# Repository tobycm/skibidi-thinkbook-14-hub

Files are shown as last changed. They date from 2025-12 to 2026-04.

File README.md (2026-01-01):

# skibidi thinkbook 14 hub

a very skibidi usb hub to clip on my laptop.

features:

- usb 3.2 gen 1 hub with gigabit ethernet
- 2 usb-a usb 3.2 gen 1 ports
- 2 usb-c usb 2.0 ports
- 3.5mm audio jack

powered by tusb8042a usb hub controller, rtl8153b gigabit ethernet controller, ch334 usb 2.0 hub controller, and pcm2704 usb dac.

designed in kicad 9

## PCB

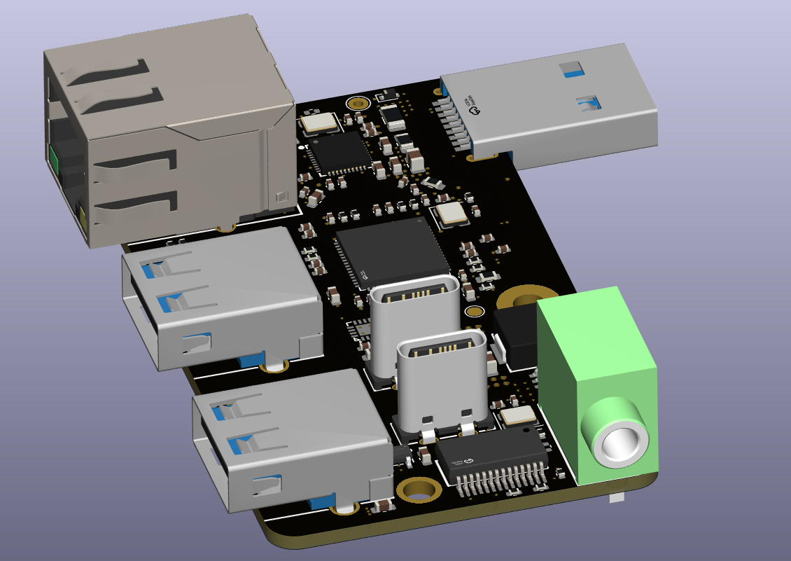
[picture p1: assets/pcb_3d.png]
pcb 3d


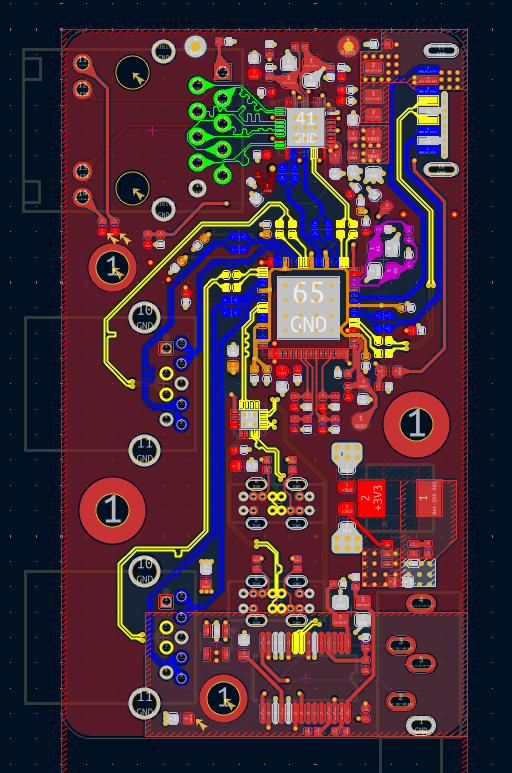
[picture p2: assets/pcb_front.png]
pcb front


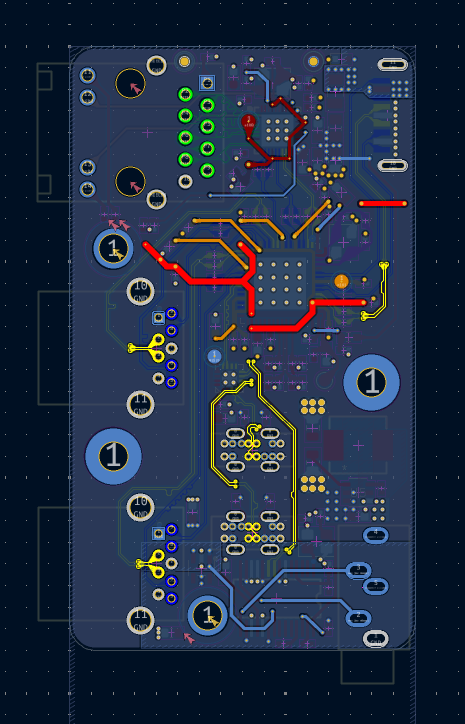
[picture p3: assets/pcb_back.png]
pcb back


## CAD

### Case

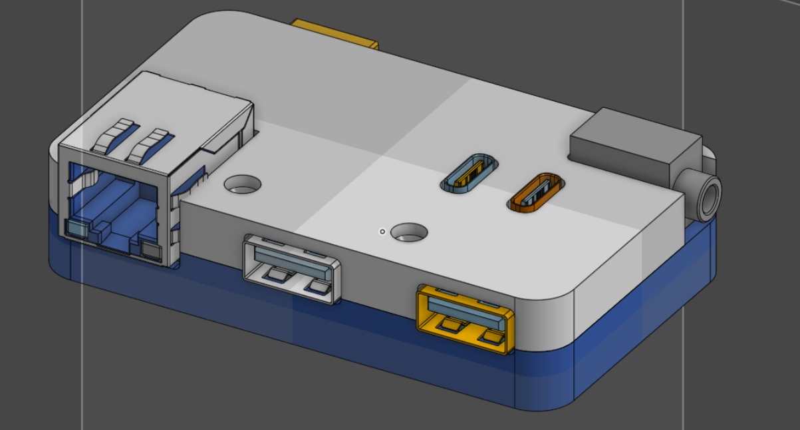
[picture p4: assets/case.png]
case


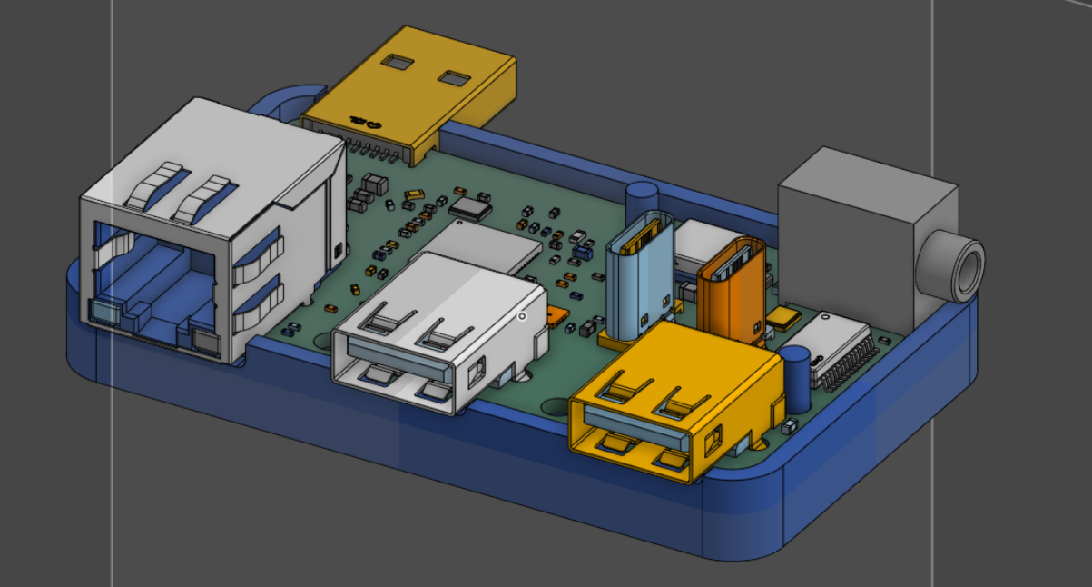
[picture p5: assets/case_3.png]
case 3


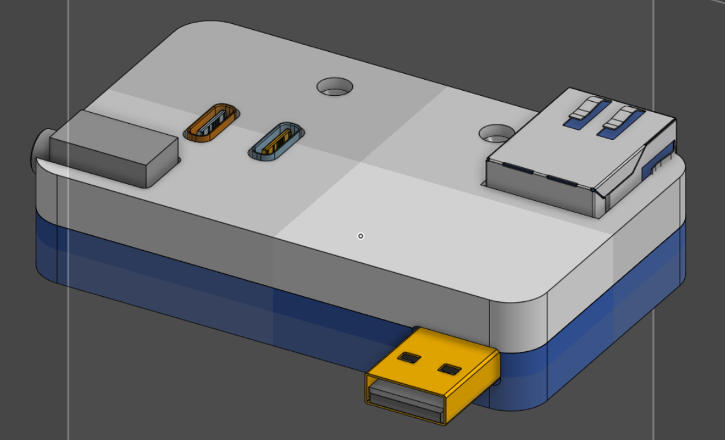
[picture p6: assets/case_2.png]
case 2


### Body

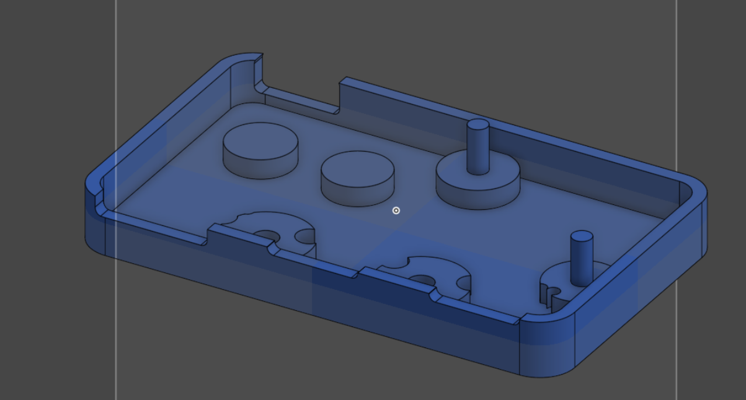
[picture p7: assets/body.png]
body


### Top

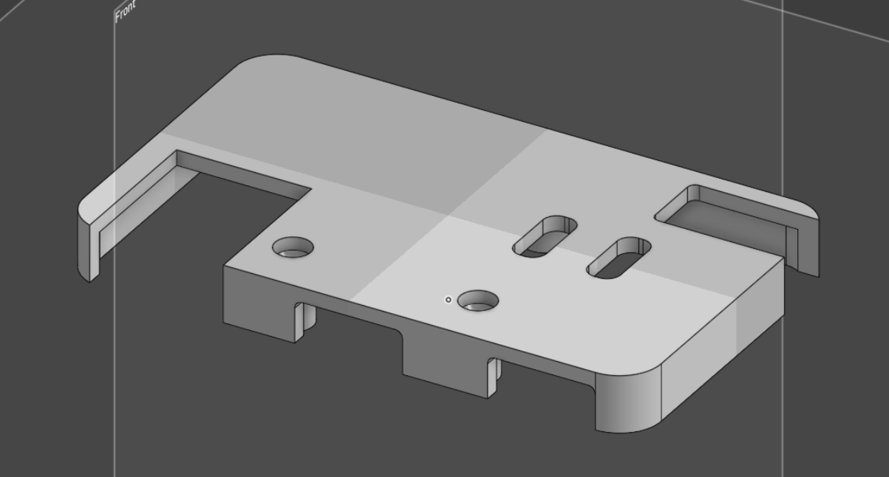
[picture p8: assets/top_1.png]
top 1


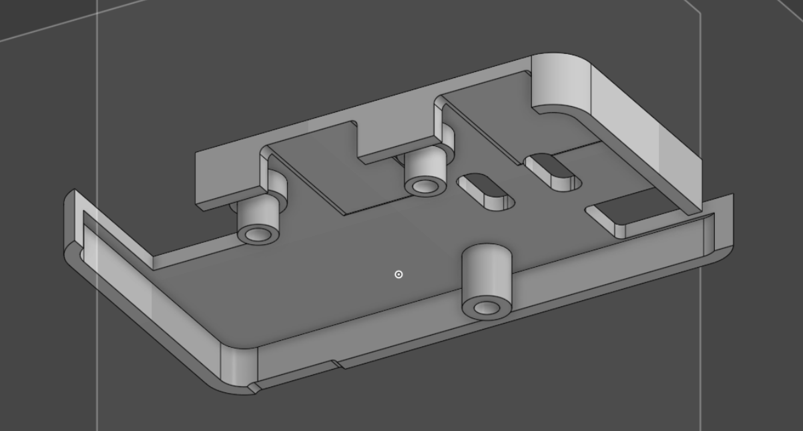
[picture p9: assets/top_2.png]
top 2


## BOM

| Item | Quantity | Total Cost | Vendor |
| :--- | :--- | :--- | :--- |
| PCB | 5 | $11.90 | JLCPCB |
| PCBA | 2 | $59.26 | JLCPCB |
| JLCPCB Shipping | 1 | $8.29 | JLCPCB |
| PJ-325C5-G | 5 | $0.90 | LCSC |
| ESD5Z5.0T1G | 20 | $0.67 | LCSC |
| BSMD1206-200-12V | 10 | $0.61 | LCSC |
| BLM21PG221SN1D | 50 | $0.83 | LCSC |
| HR911130C | 3 | $7.68 | LCSC |
| ME6211C33M5G-N | 10 | $0.47 | LCSC |
| 0603WAF4302T5E | 100 | $0.12 | LCSC |
| FRC0603F9531TS | 100 | $0.09 | LCSC |
| 0402WGF2491TCE | 200 | $0.12 | LCSC |
| HC-USB3.0-C26 | 5 | $0.53 | LCSC |
| CYA0650-4.7UH | 5 | $1.28 | LCSC |
| HC-ST-003-01-J | 20 | $2.49 | LCSC |
| TYPE-C 14PLC-H10.0 | 20 | $4.68 | LCSC |
| XL2EL89COI-111YLC-24M | 10 | $0.65 | LCSC |
| XL2EL89COI-111YLC-12M | 10 | $0.67 | LCSC |
| LCSC Shipping | 1 | $16.09 | LCSC |
| Round Hex Cap Screw kit M3 | 1 | $8.52 | Aliexpress |
| Brass Threaded Insert Nut Kit M3 | 1 | $10.54 | Aliexpress |
| **Grand Total** | **-** | **$136.39** | **-** |

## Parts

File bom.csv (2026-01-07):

Item | Quantity | Total Cost | Vendor | Link | Description
PCB | 5 | $11.90 | JLCPCB | https://jlcpcb.com/
PCBA | 2 | $59.26 | JLCPCB
JLCPCB Shipping | 1 | $8.29 | JLCPCB
PJ-325C5-G | 5 | $0.90 | LCSC | https://www.lcsc.com/product-detail/C692438.html | 3.5mm Headphone Jack 0.5A 30V Through Hole
ESD5Z5.0T1G | 20 | $0.67 | LCSC | https://www.lcsc.com/product-detail/C82044.html | 18.6VC Clamp 9.4A@8/20us Ipp ESD DIODE SOD-523
BSMD1206-200-12V | 10 | $0.61 | LCSC | https://www.lcsc.com/product-detail/C883135.html | Polymeric PTC Resettable Fuse 12V 2A Surface Mount 1206
BLM21PG221SN1D | 50 | $0.83 | LCSC | https://www.lcsc.com/product-detail/C85840.html | 220Ω@100MHz 1 Line Ferrite Bead 0805 2A 45mΩ
HR911130C | 3 | $7.68 | LCSC | https://www.lcsc.com/product-detail/C50933.html | Jack Modular Connector RJ45 Through Hole, Right Angle Shielded
ME6211C33M5G-N | 10 | $0.47 | LCSC | https://www.lcsc.com/product-detail/C82942.html | Positive Fixed 3.3V SOT-23-5 Voltage Regulators - Linear, Low Drop Out (LDO) Regulators RoHS
0603WAF4302T5E | 100 | $0.12 | LCSC | https://www.lcsc.com/product-detail/C23172.html | 43kΩ ±1% 100mW 0603 Thick Film Resistor
FRC0603F9531TS | 100 | $0.09 | LCSC | https://www.lcsc.com/product-detail/C2960722.html | 9.53kΩ ±1% 100mW 0603 Thick Film Resistor
0402WGF2491TCE | 200 | $0.12 | LCSC | https://www.lcsc.com/product-detail/C25884.html | 2.49kΩ ±1% 62.5mW 0402 Thick Film Resistor
HC-USB3.0-C26 | 5 | $0.53 | LCSC | https://www.lcsc.com/product-detail/C7501854.html | USB-A (USB TYPE-A) Receptacle Connector 9 Position Recessed Mount
CYA0650-4.7UH | 5 | $1.28 | LCSC | https://www.lcsc.com/product-detail/C5189754.html | 6A 4.7uH ±20% 8A 26mΩ SMD,7.2x6.6mm Fixed Inductors RoHS
HC-ST-003-01-J | 20 | $2.49 | LCSC | https://www.lcsc.com/product-detail/C2845330.html | USB-A (USB TYPE-A) Receptacle Connector 9 Position Right Angle
TYPE-C 14PLC-H10.0 | 20 | $4.68 | LCSC | https://www.lcsc.com/product-detail/C3151746.html | USB-C (USB TYPE-C) Receptacle Connector 14 Position Through Hole
XL2EL89COI-111YLC-24M | 10 | $0.65 | LCSC | https://www.lcsc.com/product-detail/C5444545.html | Crystal 24MHz ±10ppm 12pF SMD3225-4P
XL2EL89COI-111YLC-12M | 10 | $0.67 | LCSC | https://www.lcsc.com/product-detail/C5280578.html | Crystal 12MHz ±10ppm 12pF SMD3225-4P
Caps | 100 | $1.00 | LCSC
LCSC Shipping | 1 | $16.09 | LCSC
Round Hex Cap Screw kit M3 | 1 | $8.52 | Aliexpress | https://www.aliexpress.com/item/1005007197683325.html
Brass Threaded Insert Nut Kit M3 | 1 | $10.54 | Aliexpress | https://www.aliexpress.com/item/1005006472962973.html
skibidi thinkbook 14 hub | 1 | $137.39 |  | https://github.com/tobycm/skibidi-thinkbook-14-hub

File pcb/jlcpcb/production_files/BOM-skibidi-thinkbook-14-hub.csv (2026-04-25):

Comment | Designator | Footprint | LCSC | Quantity
100n | C14,C15,C16,C17,C2,C22,C23,C24,C25,C26,C27,C28,C29,C3,C31,C32,C33,C34,C35,C36,C4,C40,C41,C47,C48,C49,C5,C51,C6,C7,C8,C9 | C_0402_1005Metric | C307331 | 32
10u | C1,C13,C20,C30,C39,C44,C50 | C_0603_1608Metric | C19702 | 7
18p | C11,C12,C37,C38,C45,C52 | C_0402_1005Metric | C1549 | 6
1M | R1 | R_0402_1005Metric | C26083 | 1
1u | C10,C19,C46,C53,C54,C55 | C_0603_1608Metric | C15849 | 6
22 | R10,R11,R12,R13,R16,R6,R7,R9 | R_0402_1005Metric | C25092 | 8
22u | C21,C42,C43 | C_0805_2012Metric | C45783 | 3
25Mhz | Y2 | Crystal_SMD_3225-4Pin_3.2x2.5mm | C9006 | 1
4.7k | R14,R17,R18,R2,R20,R21,R27,R28,R31,R32,R33,R34,R4,R8 | R_0402_1005Metric | C25900 | 14
470 | R24,R25 | R_0402_1005Metric | C25117 | 2
56k | R35,R36,R37,R38 | R_0402_1005Metric | C25796 | 4
AP63203WU-7 | U5 | AP63203WU-7_DIO | C780769 | 1
CH334P | U4 | QFN-16_L3.0-W3.0-P0.50-BL-EP1.7 | C5373042 | 1
PCM2704CDBR | U7 | SSOP-28_L10.2-W5.3-P0.65-LS7.8-BL | C2859784 | 1
RTL8153B-VB-CG | U3 | QFN-40_L5.0-W5.0-P0.40-BL-EP3.7 | C2802072 | 1
TUSB8042AIRGCR | U2 | VQFN-64_L9.0-W9.0-P0.50-TL-EP6.0 | C2860610 | 1

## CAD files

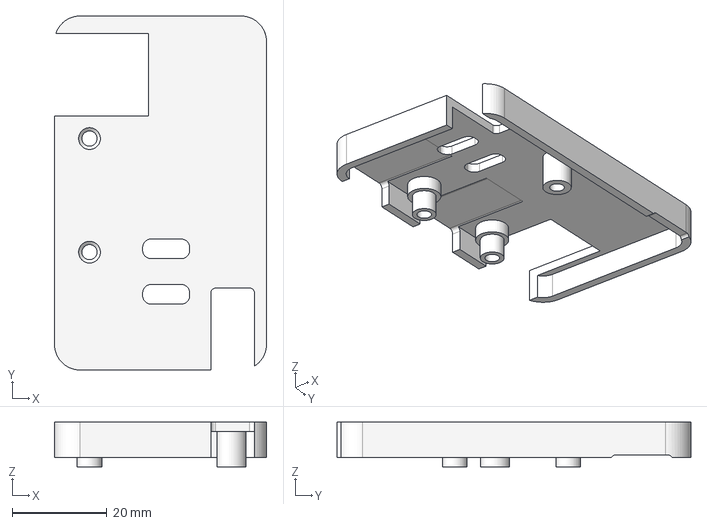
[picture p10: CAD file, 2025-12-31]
cad/top.step
44.8 x 74.8 x 9.48 mm

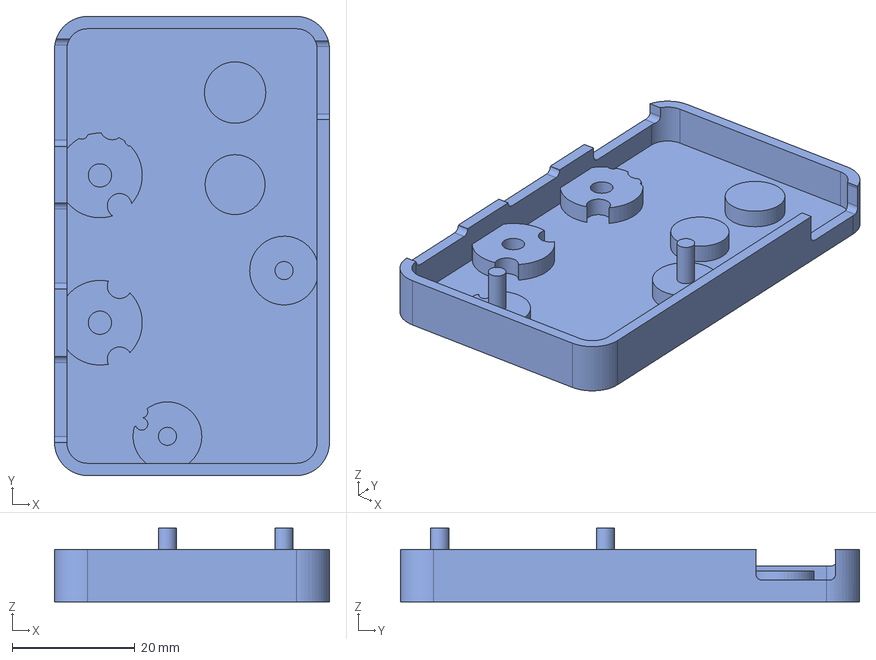
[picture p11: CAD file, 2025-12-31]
cad/body.step
44.8 x 74.8 x 12.0 mm

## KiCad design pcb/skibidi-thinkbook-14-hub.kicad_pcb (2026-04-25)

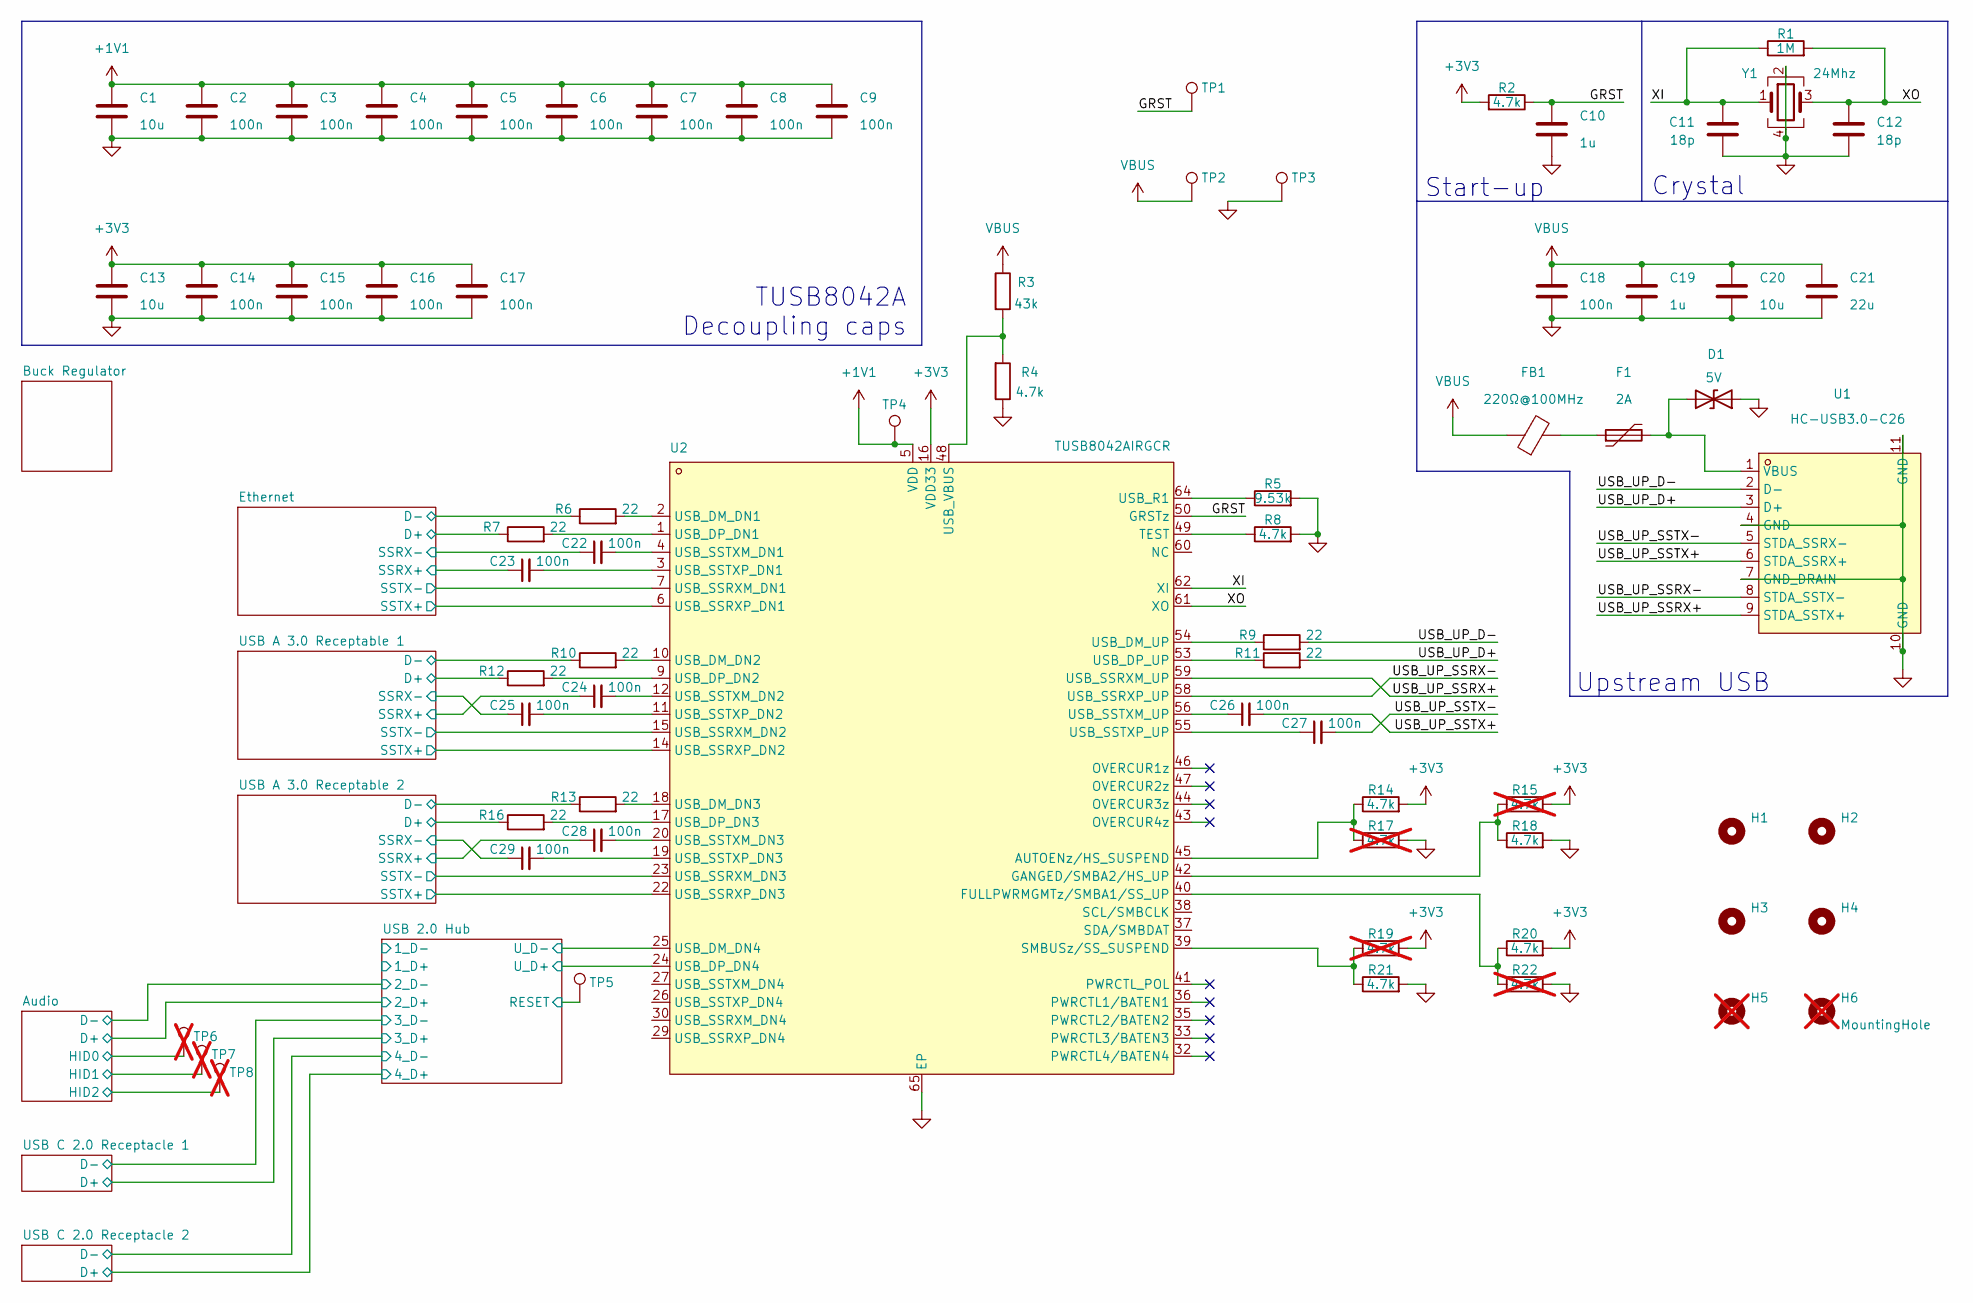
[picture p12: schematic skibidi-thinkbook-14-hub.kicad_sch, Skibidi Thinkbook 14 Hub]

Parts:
C1, C13, C20: 10u; C_0603_1608Metric; LCSC Part # C19702
C2, C3, C4, C5, C6, C7, C8, C9, C14, C15, C16, C17, C18, C22, C23, C24, C25, C26, C27, C28, C29: 100n; C_0402_1005Metric; LCSC Part # C307331
C10, C19: 1u; C_0603_1608Metric; LCSC Part # C15849
C11, C12: 18p; C_0402_1005Metric; LCSC Part # C1549
C21: 22u; C_0805_2012Metric; LCSC Part # C45783
D1: 5V; D_SOD-523; LCSC Part # C82044
F1: 2A; Fuse_1206_3216Metric; LCSC Part # C883135
FB1: 220Ω@100MHz; R_0805_2012Metric_Pad1.20x1.40mm_HandSolder; LCSC Part # C85840
H1, H2, H3, H4: MountingHole; MountingHole_3.2mm_M3_Pad
H5, H6: MountingHole; MountingHole_3.2mm_M3_Pad; not fitted
R1: 1M; R_0402_1005Metric; LCSC Part # C26083
R2, R4, R8, R14, R18, R20, R21: 4.7k; R_0402_1005Metric; LCSC Part # C25900
R3: 43k; R_0603_1608Metric; LCSC Part # C23172
R5: 9.53k; R_0603_1608Metric; LCSC Part # C2960722
R6, R7, R9, R10, R11, R12, R13, R16: 22; R_0402_1005Metric; LCSC Part # C25092
R15, R17, R19, R22: 4.7k; R_0402_1005Metric; LCSC Part # C25900; not fitted
TP1, TP4, TP5: TestPoint; TestPoint_Pad_D1.5mm
TP2, TP3: TestPoint; TestPoint_Pad_D2.0mm
TP6, TP7, TP8: TestPoint; TestPoint_Pad_D1.5mm; not fitted
U1: HC-USB3.0-C26; USB-3.0-A-SMD_HC-USB3.0-C26; LCSC Part C7501854
U2: TUSB8042AIRGCR; VQFN-64_L9.0-W9.0-P0.50-TL-EP6.0; LCSC Part C2860610
Y1: 24Mhz; Crystal_SMD_3225-4Pin_3.2x2.5mm; LCSC Part # C5444545

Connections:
+1V1: C1.1, C2.1, C3.1, C4.1, C5.1, C6.1, C7.1, C8.1, C9.1, TP4.1, U2.5 (VDD), U2.8 (VDD), U2.13 (VDD), U2.21 (VDD), U2.28 (VDD), U2.31 (VDD), U2.51 (VDD), U2.57 (VDD)
+3V3: C13.1, C14.1, C15.1, C16.1, C17.1, R2.2, R14.2, R15.2, R19.2, R20.2, U2.16 (VDD33), U2.34 (VDD33), U2.52 (VDD33), U2.63 (VDD33); also elsewhere on the board
/Ethernet/D+: R7.1; also elsewhere on the board
/Ethernet/D-: R6.1; also elsewhere on the board
/Ethernet/SSRX+: C23.1; also elsewhere on the board
/Ethernet/SSRX-: C22.1; also elsewhere on the board
/Ethernet/SSTX+: U2.6 (USB_SSRXP_DN1); also elsewhere on the board
/Ethernet/SSTX-: U2.7 (USB_SSRXM_DN1); also elsewhere on the board
/GRST: C10.1, R2.1, TP1.1, U2.50 (GRSTz)
/USB 2.0 Hub/RESET: TP5.1; also elsewhere on the board
/USB 2.0 Hub/U_D+: U2.24 (USB_DP_DN4); also elsewhere on the board
/USB 2.0 Hub/U_D-: U2.25 (USB_DM_DN4); also elsewhere on the board
/USB A 3.0 Receptable 1/D+: R12.1; also elsewhere on the board
/USB A 3.0 Receptable 1/D-: R10.1; also elsewhere on the board
/USB A 3.0 Receptable 1/SSRX+: C24.1; also elsewhere on the board
/USB A 3.0 Receptable 1/SSRX-: C25.1; also elsewhere on the board
/USB A 3.0 Receptable 1/SSTX+: U2.14 (USB_SSRXP_DN2); also elsewhere on the board
/USB A 3.0 Receptable 1/SSTX-: U2.15 (USB_SSRXM_DN2); also elsewhere on the board
/USB A 3.0 Receptable 2/D+: R16.1; also elsewhere on the board
/USB A 3.0 Receptable 2/D-: R13.1; also elsewhere on the board
/USB A 3.0 Receptable 2/SSRX+: C28.1; also elsewhere on the board
/USB A 3.0 Receptable 2/SSRX-: C29.1; also elsewhere on the board
/USB A 3.0 Receptable 2/SSTX+: U2.22 (USB_SSRXP_DN3); also elsewhere on the board
/USB A 3.0 Receptable 2/SSTX-: U2.23 (USB_SSRXM_DN3); also elsewhere on the board
/USB_UP_D+: R11.2, U1.3 (D+)
/USB_UP_D-: R9.2, U1.2 (D-)
/USB_UP_SSRX+: U1.9 (STDA_SSTX+), U2.59 (USB_SSRXM_UP)
/USB_UP_SSRX-: U1.8 (STDA_SSTX-), U2.58 (USB_SSRXP_UP)
/USB_UP_SSTX+: C26.2, U1.6 (STDA_SSRX+)
/USB_UP_SSTX-: C27.2, U1.5 (STDA_SSRX-)
/XI: C11.1, R1.1, U2.62 (XI), Y1.1
/XO: C12.1, R1.2, U2.61 (XO), Y1.3
GND: C1.2, C2.2, C3.2, C4.2, C5.2, C6.2, C7.2, C8.2, C9.2, C10.2, C11.2, C12.2, C13.2, C14.2, C15.2, C16.2, C17.2, C18.2, C19.2, C20.2, C21.2, D1.1 (A1), R4.1, R5.2, R8.2, R17.2, R18.2, R21.2, R22.2, TP3.1, U1.4 (GND), U1.7 (GND_DRAIN), U1.10 (GND), U1.11 (GND), U2.65 (EP), Y1.2, Y1.4; also elsewhere on the board
unnamed: D1.2 (A2), F1.2, U1.1 (VBUS)
unnamed: F1.1, FB1.2
unnamed: R14.1, R17.1, U2.45 (AUTOENz/HS_SUSPEND)
unnamed: R20.1, R22.1, U2.40 (FULLPWRMGMTz/SMBA1/SS_UP)
unnamed: R15.1, R18.1, U2.42 (GANGED/SMBA2/HS_UP)
unnamed: R19.1, R21.1, U2.39 (SMBUSz/SS_SUSPEND)
unnamed: R8.1, U2.49 (TEST)
unnamed: R6.2, U2.2 (USB_DM_DN1)
unnamed: R10.2, U2.10 (USB_DM_DN2)
unnamed: R13.2, U2.18 (USB_DM_DN3)
unnamed: R9.1, U2.54 (USB_DM_UP)
unnamed: R7.2, U2.1 (USB_DP_DN1)
unnamed: R12.2, U2.9 (USB_DP_DN2)
unnamed: R16.2, U2.17 (USB_DP_DN3)
unnamed: R11.1, U2.53 (USB_DP_UP)
unnamed: R5.1, U2.64 (USB_R1)
unnamed: C22.2, U2.4 (USB_SSTXM_DN1)
unnamed: C24.2, U2.12 (USB_SSTXM_DN2)
unnamed: C28.2, U2.20 (USB_SSTXM_DN3)
unnamed: C26.1, U2.56 (USB_SSTXM_UP)
unnamed: C23.2, U2.3 (USB_SSTXP_DN1)
unnamed: C25.2, U2.11 (USB_SSTXP_DN2)
unnamed: C29.2, U2.19 (USB_SSTXP_DN3)
unnamed: C27.1, U2.55 (USB_SSTXP_UP)
unnamed: R3.2, R4.2, U2.48 (USB_VBUS)
VBUS: C18.1, C19.1, C20.1, C21.1, FB1.1, R3.1, TP2.1; also elsewhere on the board

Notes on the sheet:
TUSB8042A Decoupling caps
Start-up
Crystal
Upstream USB

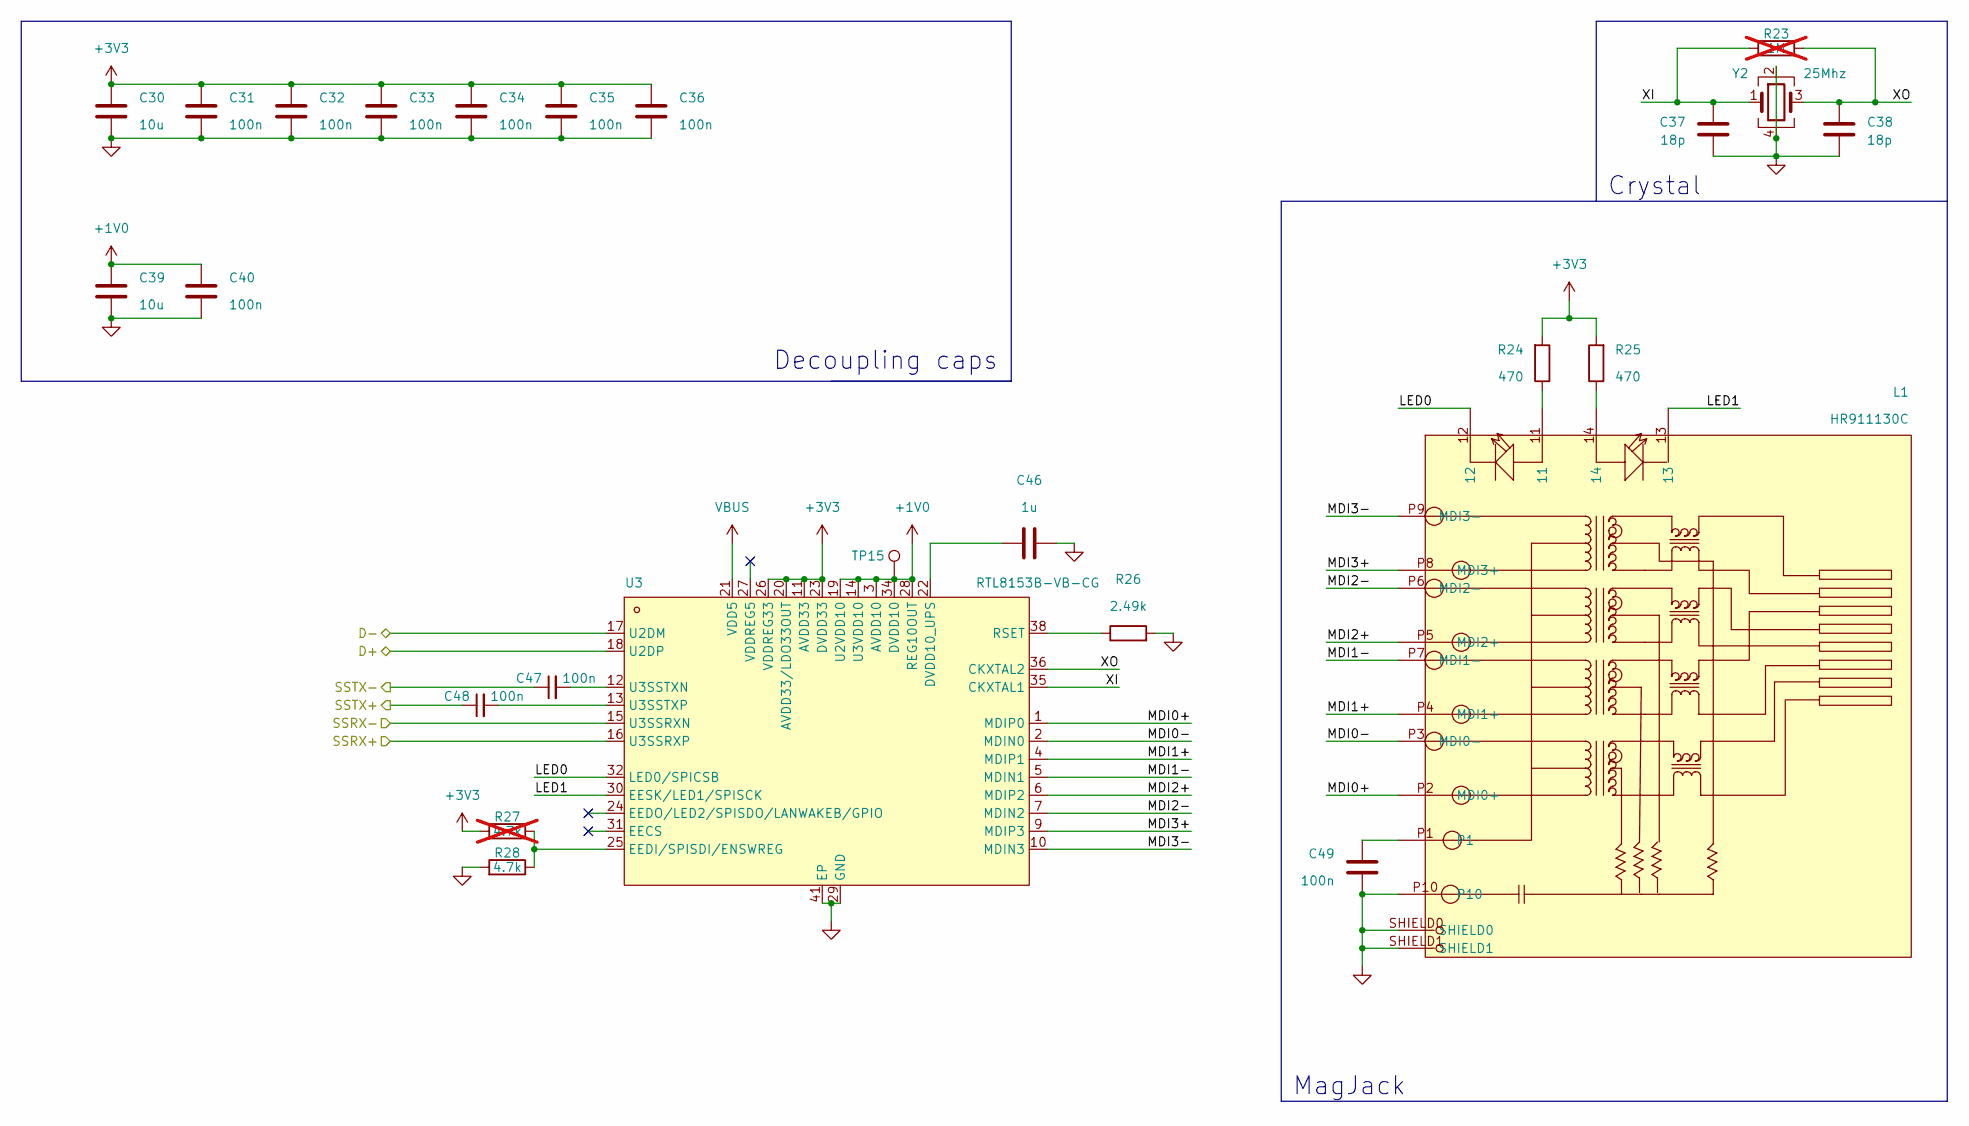
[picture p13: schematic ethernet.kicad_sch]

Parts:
C30, C39: 10u; C_0603_1608Metric; LCSC Part # C19702
C31, C32, C33, C34, C35, C36, C40, C47, C48, C49: 100n; C_0402_1005Metric; LCSC Part # C307331
C37, C38: 18p; C_0402_1005Metric; LCSC Part # C1549
C46: 1u; C_0603_1608Metric; LCSC Part # C15849
L1: HR911130C; RJ45-TH_HR911130C; LCSC Part C50933
R23: 1M; R_0402_1005Metric; LCSC Part # C26083; not fitted
R24, R25: 470; R_0402_1005Metric; LCSC Part # C25117
R26: 2.49k; R_0402_1005Metric; LCSC Part # C25884
R27: 4.7k; R_0402_1005Metric; LCSC Part # C25900; not fitted
R28: 4.7k; R_0402_1005Metric; LCSC Part # C25900
TP15: TestPoint; TestPoint_Pad_D1.5mm
U3: RTL8153B-VB-CG; QFN-40_L5.0-W5.0-P0.40-BL-EP3.7; LCSC Part C2802072
Y2: 25Mhz; Crystal_SMD_3225-4Pin_3.2x2.5mm; LCSC Part # C9006

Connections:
+1V0: C39.1, C40.1, TP15.1, U3.3 (AVDD10), U3.8 (AVDD10), U3.14 (U3VDD10), U3.19 (U2VDD10), U3.28 (REG10OUT), U3.34 (DVDD10), U3.37 (AVDD10)
+3V3: C30.1, C31.1, C32.1, C33.1, C34.1, C35.1, C36.1, R24.2, R25.2, R27.2, U3.11 (AVDD33), U3.20 (AVDD33/LDO33OUT), U3.23 (DVDD33), U3.26 (VDDREG33), U3.33 (DVDD33), U3.39 (AVDD33), U3.40 (AVDD33); also elsewhere on the board
/Ethernet/D+: U3.18 (U2DP); also elsewhere on the board
/Ethernet/D-: U3.17 (U2DM); also elsewhere on the board
/Ethernet/LED0: L1.12, U3.32 (LED0/SPICSB)
/Ethernet/LED1: L1.13, U3.30 (EESK/LED1/SPISCK)
/Ethernet/MDI0+: L1.P2 (MDI0+), U3.1 (MDIP0)
/Ethernet/MDI0-: L1.P3 (MDI0-), U3.2 (MDIN0)
/Ethernet/MDI1+: L1.P4 (MDI1+), U3.4 (MDIP1)
/Ethernet/MDI1-: L1.P7 (MDI1-), U3.5 (MDIN1)
/Ethernet/MDI2+: L1.P5 (MDI2+), U3.6 (MDIP2)
/Ethernet/MDI2-: L1.P6 (MDI2-), U3.7 (MDIN2)
/Ethernet/MDI3+: L1.P8 (MDI3+), U3.9 (MDIP3)
/Ethernet/MDI3-: L1.P9 (MDI3-), U3.10 (MDIN3)
/Ethernet/SSRX+: U3.16 (U3SSRXP); also elsewhere on the board
/Ethernet/SSRX-: U3.15 (U3SSRXN); also elsewhere on the board
/Ethernet/SSTX+: C48.1; also elsewhere on the board
/Ethernet/SSTX-: C47.1; also elsewhere on the board
/Ethernet/XI: C37.1, R23.1, U3.35 (CKXTAL1), Y2.1
/Ethernet/XO: C38.1, R23.2, U3.36 (CKXTAL2), Y2.3
GND: C30.2, C31.2, C32.2, C33.2, C34.2, C35.2, C36.2, C37.2, C38.2, C39.2, C40.2, C46.2, C49.2, L1.P10, L1.SHIELD0, L1.SHIELD1, R26.2, R28.2, U3.29 (GND), U3.41 (EP), Y2.2, Y2.4; also elsewhere on the board
unnamed: C49.1, L1.P1
unnamed: L1.11, R24.1
unnamed: L1.14, R25.1
unnamed: C46.1, U3.22 (DVDD10_UPS)
unnamed: R27.1, R28.1, U3.25 (EEDI/SPISDI/ENSWREG)
unnamed: R26.1, U3.38 (RSET)
unnamed: C47.2, U3.12 (U3SSTXN)
unnamed: C48.2, U3.13 (U3SSTXP)
VBUS: U3.21 (VDD5); also elsewhere on the board

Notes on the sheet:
MagJack
Decoupling caps
Crystal

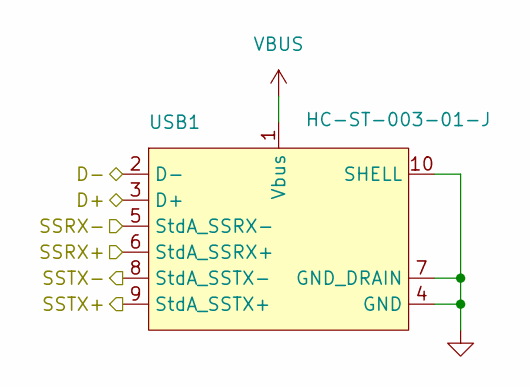
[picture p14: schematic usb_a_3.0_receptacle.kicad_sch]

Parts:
USB1: HC-ST-003-01-J; USB-3.0-A-TH_HC-ST-003-01-Z; LCSC Part C2845330

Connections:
/USB A 3.0 Receptable 1/D+: USB1.3 (D+); also elsewhere on the board
/USB A 3.0 Receptable 1/D-: USB1.2 (D-); also elsewhere on the board
/USB A 3.0 Receptable 1/SSRX+: USB1.6 (StdA_SSRX+); also elsewhere on the board
/USB A 3.0 Receptable 1/SSRX-: USB1.5 (StdA_SSRX-); also elsewhere on the board
/USB A 3.0 Receptable 1/SSTX+: USB1.9 (StdA_SSTX+); also elsewhere on the board
/USB A 3.0 Receptable 1/SSTX-: USB1.8 (StdA_SSTX-); also elsewhere on the board
GND: USB1.4 (GND), USB1.7 (GND_DRAIN), USB1.10 (SHELL), USB1.11 (SHELL); also elsewhere on the board
VBUS: USB1.1 (Vbus); also elsewhere on the board

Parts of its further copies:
USB2: HC-ST-003-01-J; USB-3.0-A-TH_HC-ST-003-01-Z; LCSC Part C2845330

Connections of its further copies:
/USB A 3.0 Receptable 2/D+: USB2.3 (D+); also elsewhere on the board
/USB A 3.0 Receptable 2/D-: USB2.2 (D-); also elsewhere on the board
/USB A 3.0 Receptable 2/SSRX+: USB2.6 (StdA_SSRX+); also elsewhere on the board
/USB A 3.0 Receptable 2/SSRX-: USB2.5 (StdA_SSRX-); also elsewhere on the board
/USB A 3.0 Receptable 2/SSTX+: USB2.9 (StdA_SSTX+); also elsewhere on the board
/USB A 3.0 Receptable 2/SSTX-: USB2.8 (StdA_SSTX-); also elsewhere on the board
GND: USB2.4 (GND), USB2.7 (GND_DRAIN), USB2.10 (SHELL), USB2.11 (SHELL); also elsewhere on the board
VBUS: USB2.1 (Vbus); also elsewhere on the board

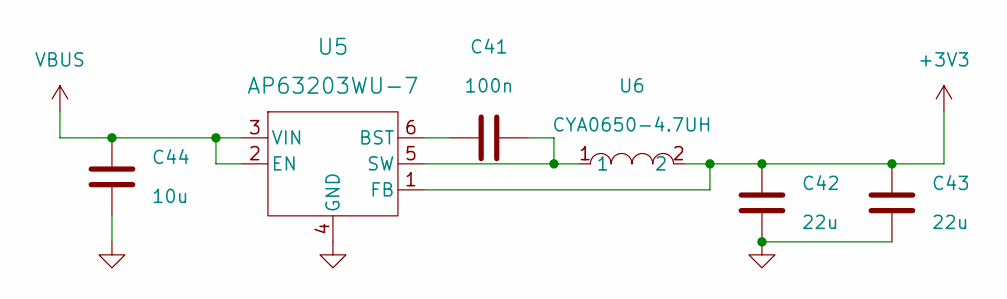
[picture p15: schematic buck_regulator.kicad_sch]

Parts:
C41: 100n; C_0402_1005Metric; LCSC Part # C307331
C42, C43: 22u; C_0805_2012Metric; LCSC Part # C45783
C44: 10u; C_0603_1608Metric; LCSC Part # C19702
U5: AP63203WU-7; AP63203WU-7_DIO; LCSC Part # C780769
U6: CYA0650-4.7UH; IND-SMD_L7.2-W6.6_GPSR07X0; LCSC Part C5189754

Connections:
+3V3: C42.1, C43.1, U5.1 (FB), U6.2; also elsewhere on the board
GND: C42.2, C43.2, C44.2, U5.4 (GND); also elsewhere on the board
unnamed: C41.1, U5.6 (BST)
unnamed: C41.2, U5.5 (SW), U6.1
VBUS: C44.1, U5.2 (EN), U5.3 (VIN); also elsewhere on the board

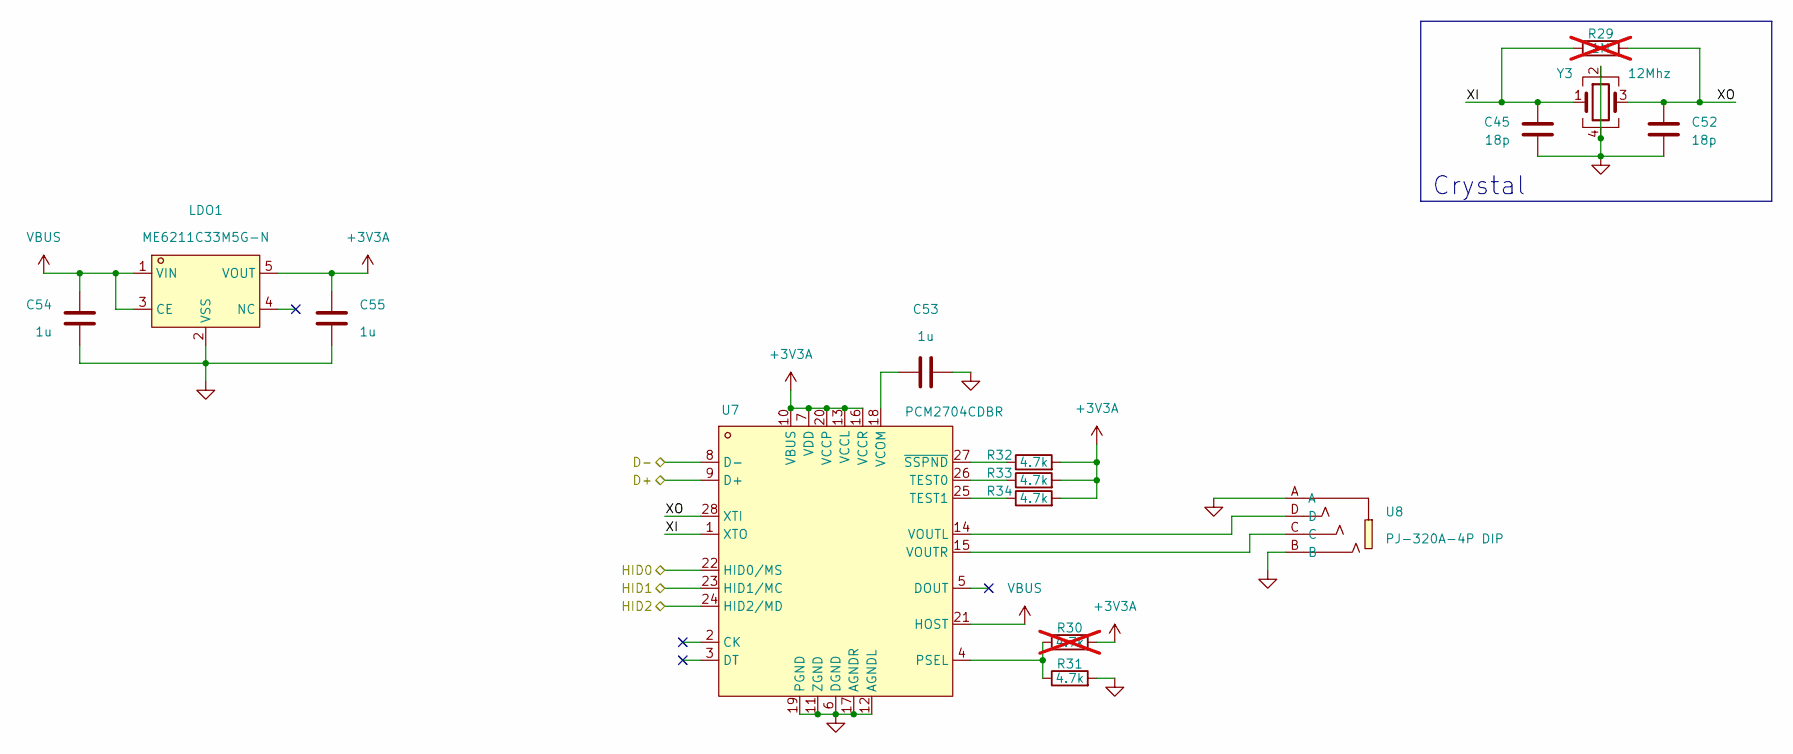
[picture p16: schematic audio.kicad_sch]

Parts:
C45, C52: 18p; C_0402_1005Metric; LCSC Part # C1549
C53, C54, C55: 1u; C_0603_1608Metric; LCSC Part # C15849
LDO1: ME6211C33M5G-N; SOT-23-5_L3.0-W1.7-P0.95-LS2.8-BL; LCSC Part C82942
R29: 1M; R_0402_1005Metric; LCSC Part # C26083; not fitted
R30: 4.7k; R_0402_1005Metric; LCSC Part # C25900; not fitted
R31, R32, R33, R34: 4.7k; R_0402_1005Metric; LCSC Part # C25900
U7: PCM2704CDBR; SSOP-28_L10.2-W5.3-P0.65-LS7.8-BL; LCSC Part C2859784
U8: PJ-320A-4P DIP; AUDIO-TH_PJ-320A-4P-DIP; LCSC Part C18185602
Y3: 12Mhz; Crystal_SMD_3225-4Pin_3.2x2.5mm; LCSC Part # C5280578

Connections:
+3V3A: C55.1, LDO1.5 (VOUT), R30.2, R32.2, R33.2, R34.2, U7.7 (VDD), U7.10 (VBUS), U7.13 (VCCL), U7.16 (VCCR), U7.20 (VCCP)
/Audio/D+: U7.9 (D+); also elsewhere on the board
/Audio/D-: U7.8 (D-); also elsewhere on the board
/Audio/HID0: U7.22 (HID0/MS)
/Audio/HID1: U7.23 (HID1/MC)
/Audio/HID2: U7.24 (HID2/MD)
/Audio/XI: C45.1, R29.1, U7.1 (XTO), Y3.1
/Audio/XO: C52.1, R29.2, U7.28 (XTI), Y3.3
GND: C45.2, C52.2, C53.2, C54.2, C55.2, LDO1.2 (VSS), R31.2, U7.6 (DGND), U7.11 (ZGND), U7.12 (AGNDL), U7.17 (AGNDR), U7.19 (PGND), U8.A, U8.B, Y3.2, Y3.4; also elsewhere on the board
unnamed: R30.1, R31.1, U7.4 (PSEL)
unnamed: R33.1, U7.26 (TEST0)
unnamed: R34.1, U7.25 (TEST1)
unnamed: C53.1, U7.18 (VCOM)
unnamed: U7.14 (VOUTL), U8.D
unnamed: U7.15 (VOUTR), U8.C
unnamed: R32.1, U7.27 (~SSPND)
VBUS: C54.1, LDO1.1 (VIN), LDO1.3 (CE), U7.21 (HOST); also elsewhere on the board

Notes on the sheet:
Crystal

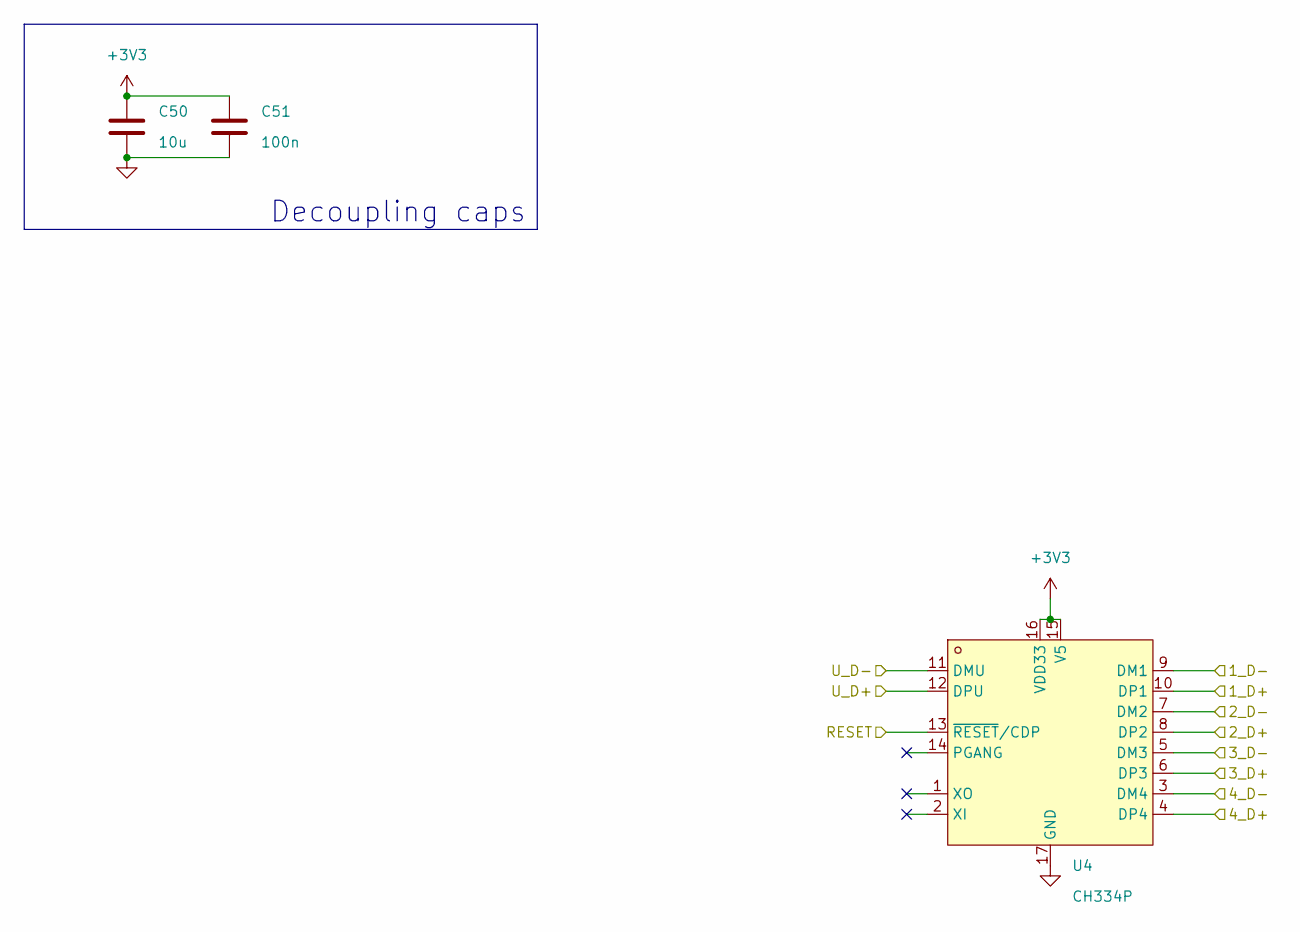
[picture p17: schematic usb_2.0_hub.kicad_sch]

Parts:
C50: 10u; C_0603_1608Metric; LCSC Part # C19702
C51: 100n; C_0402_1005Metric; LCSC Part # C307331
U4: CH334P; QFN-16_L3.0-W3.0-P0.50-BL-EP1.7; LCSC Part C5373042

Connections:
+3V3: C50.1, C51.1, U4.15 (V5), U4.16 (VDD33); also elsewhere on the board
/Audio/D+: U4.8 (DP2); also elsewhere on the board
/Audio/D-: U4.7 (DM2); also elsewhere on the board
/USB 2.0 Hub/1_D+: U4.10 (DP1)
/USB 2.0 Hub/1_D-: U4.9 (DM1)
/USB 2.0 Hub/3_D+: U4.6 (DP3); also elsewhere on the board
/USB 2.0 Hub/3_D-: U4.5 (DM3); also elsewhere on the board
/USB 2.0 Hub/4_D+: U4.4 (DP4); also elsewhere on the board
/USB 2.0 Hub/4_D-: U4.3 (DM4); also elsewhere on the board
/USB 2.0 Hub/RESET: U4.13 (~RESET/CDP); also elsewhere on the board
/USB 2.0 Hub/U_D+: U4.12 (DPU); also elsewhere on the board
/USB 2.0 Hub/U_D-: U4.11 (DMU); also elsewhere on the board
GND: C50.2, C51.2, U4.17 (GND); also elsewhere on the board

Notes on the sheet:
Decoupling caps

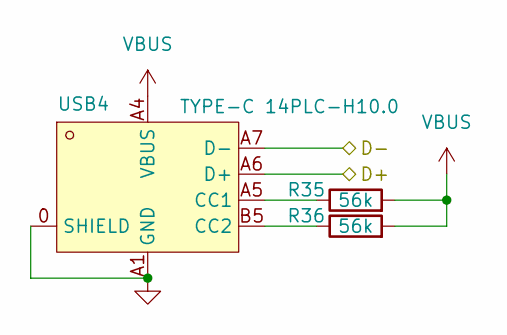
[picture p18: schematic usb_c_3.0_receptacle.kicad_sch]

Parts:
R35, R36: 56k; R_0402_1005Metric; LCSC Part # C25796
USB4: TYPE-C 14PLC-H10.0; USB-C-TH_SHOUHAN_TYPE-C-14PLC-H10.0; LCSC Part C3151746

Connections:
/USB 2.0 Hub/3_D+: USB4.A6 (D+), USB4.B6 (D+); also elsewhere on the board
/USB 2.0 Hub/3_D-: USB4.A7 (D-), USB4.B7 (D-); also elsewhere on the board
GND: USB4.0 (SHIELD), USB4.A1 (GND), USB4.A12 (GND), USB4.B1 (GND), USB4.B12 (GND); also elsewhere on the board
unnamed: R35.1, USB4.A5 (CC1)
unnamed: R36.1, USB4.B5 (CC2)
VBUS: R35.2, R36.2, USB4.A4 (VBUS), USB4.A9 (VBUS), USB4.B4 (VBUS), USB4.B9 (VBUS); also elsewhere on the board

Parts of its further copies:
R37, R38: 56k; R_0402_1005Metric; LCSC Part # C25796
USB5: TYPE-C 14PLC-H10.0; USB-C-TH_SHOUHAN_TYPE-C-14PLC-H10.0; LCSC Part C3151746

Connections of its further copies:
/USB 2.0 Hub/4_D+: USB5.A6 (D+), USB5.B6 (D+); also elsewhere on the board
/USB 2.0 Hub/4_D-: USB5.A7 (D-), USB5.B7 (D-); also elsewhere on the board
GND: USB5.0 (SHIELD), USB5.A1 (GND), USB5.A12 (GND), USB5.B1 (GND), USB5.B12 (GND); also elsewhere on the board
unnamed: R37.1, USB5.A5 (CC1)
unnamed: R38.1, USB5.B5 (CC2)
VBUS: R37.2, R38.2, USB5.A4 (VBUS), USB5.A9 (VBUS), USB5.B4 (VBUS), USB5.B9 (VBUS); also elsewhere on the board

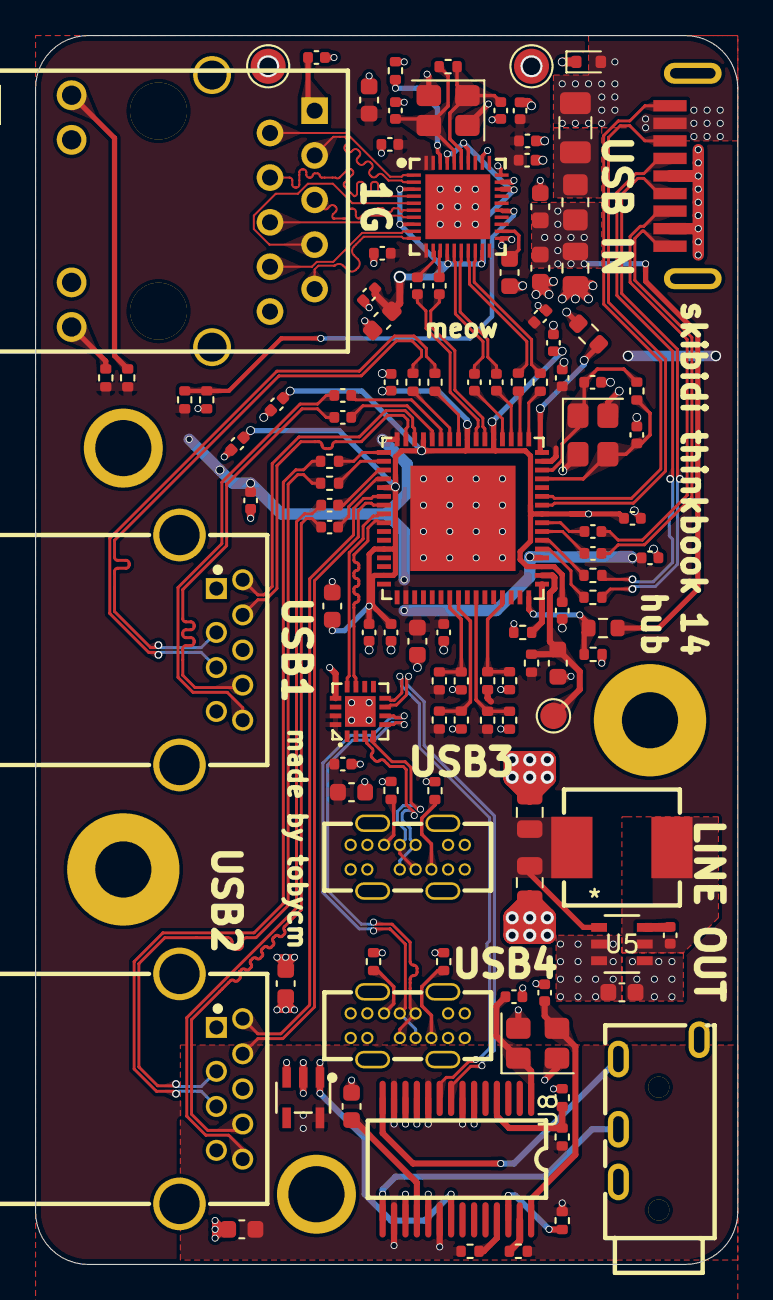
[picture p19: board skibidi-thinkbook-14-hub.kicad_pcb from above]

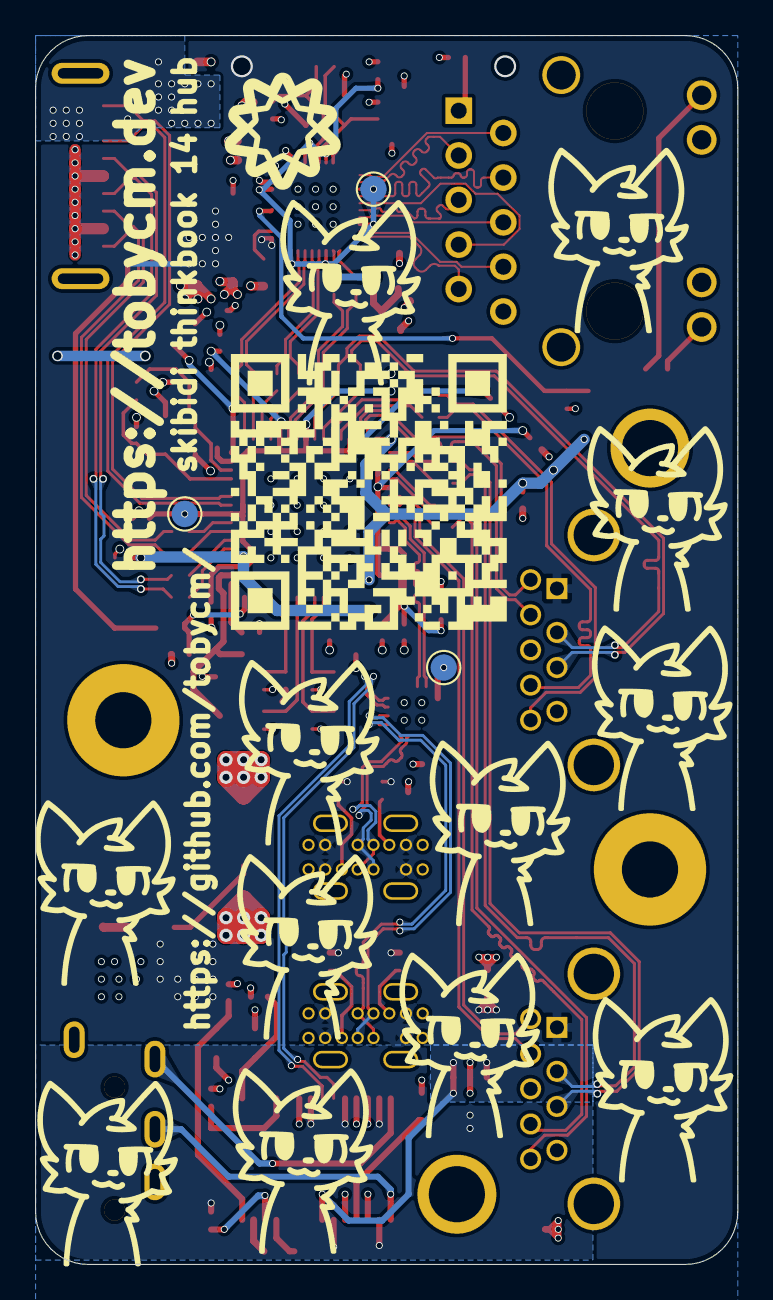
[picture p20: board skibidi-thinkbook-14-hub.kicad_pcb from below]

Board: 4 copper layers, 40.0 x 70.0 mm, 121 parts (3 on the bottom side), 102 nets.

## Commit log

2025-12-30 pcb done!
    [audio.kicad_sch, buck_regulator.kicad_sch, ethernet.kicad_sch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]
2025-12-31 add cad and readme. update pcb a bit too
    [body.step, skibidi-thinkbook-14-hub.kicad_pcb, top.step]
2026-01-01 added bom to readme, completed project
    [audio.kicad_sch, skibidi-thinkbook-14-hub.kicad_pcb]
2026-01-07 gitignored my bom :c
    add gerber zip
    [BOM-skibidi-thinkbook-14-hub.csv, bom.csv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]
2026-04-25 add gerbers
    [BOM-skibidi-thinkbook-14-hub.csv, audio.kicad_sch, skibidi-thinkbook-14-hub.kicad_pcb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]
